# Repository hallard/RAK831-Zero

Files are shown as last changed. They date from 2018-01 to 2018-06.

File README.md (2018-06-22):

# Raspberry PI Zero RAK831 Lora Gateway Shield

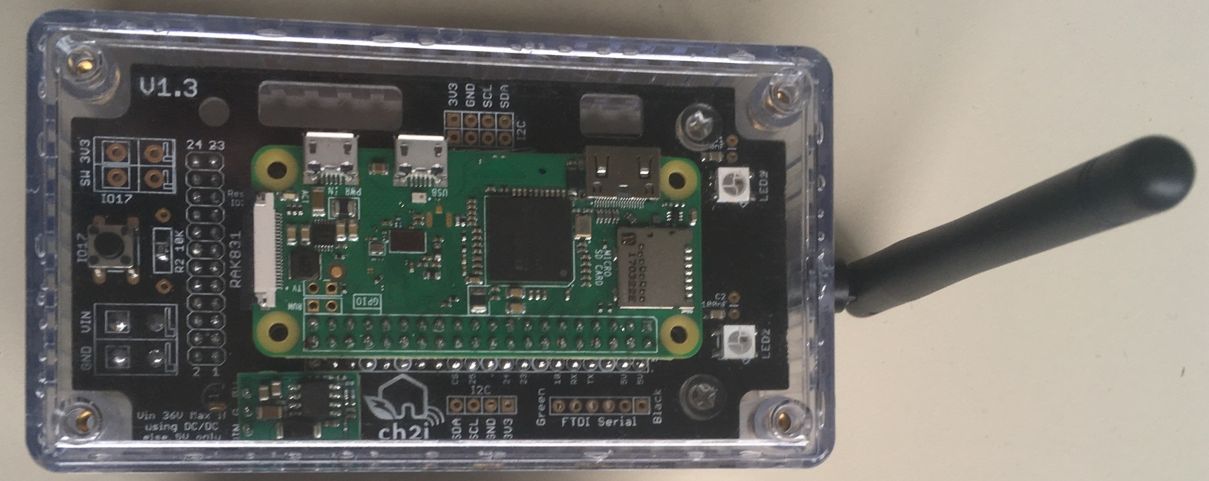
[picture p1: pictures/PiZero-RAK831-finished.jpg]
Full
     

This shield has been created to help wiring between Raspberry PI Zero and [RAK831][10] LoraWan concentrator Gateway and to be able to put the whole thing into a enclosure..

Then I decided to add some funky stuff like:

## Features (tested, working fine)

**Major updates in V1.5a**

 - Added connector to put a [Tiny GPS][46] breakout board 
 - Added switch/jumpers to select PI Serial to be connected to FTDI connector or from GPS RX/TX
 - Added footprint for RTC components or [Adafruit Breakout][47] (when used in local LoRaWAN server without Internet connexion)
 - Added a LED on ~~GPIO4~~ GPIO26 to light when GW is off so we can remove power safely (or whatever purpose)
 - Connected GPS PPS signal on GPIO4 and added a LED on this signal
 - **due to space constraints because of new features, some options to put PTH components have been removed**

**Minor tweaks in V1.4**

 - Labeling error on top silk for Murata OKI-78SR-5 (VIN VOUT were revesed) but correct on bottom silk
 - Added solder bat to be able to reverse 3V3/GND and/or SCL/SDA on I2C-1 connector 
 - Moved FTDI connector to lower position
 - Added I2C connector SILK number to identify them better
 - Added a LED on GPIO4 to light when GW is off so we can remove power safely

**Minor tweaks in V1.3b**

 - Reversed side of Murata OKI-78SR-5 to let some place for big OLED
 - Changed solder pad default power to use DC/DC 
 - Inversed the 2 OLED connectors to better seeing of RAK LED
 - Adjusted opening to see RAK LED to a better position

**Since V1.3**

 - Push button on GPIO17 to be able to shutdown PI Locally
 - Added FTDI connector to be able to take hand on PI console when in enclosure (lost network or whatever, no more need to get all off the enclosure and connect HDMI cable to see what's going on)
 - Added footprint for excellent Murata OKI-78SR-5 DC/DC 5V
 - Footprint for [RAK831][10] LoraWan concentrator (main goal)
 - I2C connectors to be able to add internal/external sensors or OLED such as BME280, SI7021, HTU21D SSD1306
 - Power with terminal block
 - 2 visual WS2812B Leds
 - Easy to build and solder, 0805 or PTH components
 - Holes to fix board on enclosure or other support
 - quick fix connector, you can plug/unplug PI Zero without soldering

Tiny GPS breakout board, buy [there][46]   
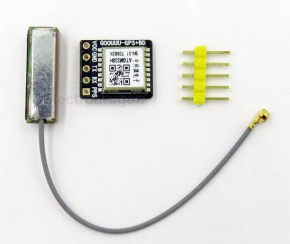
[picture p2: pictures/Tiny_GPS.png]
Tiny GPS Breakout
 

Tiny Adafruit RTC board, buy [there][47]    

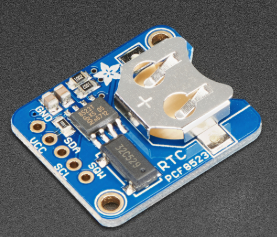
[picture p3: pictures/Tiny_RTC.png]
RTC Breakout
 

## Detailed Description

No specific documentation for now, it's just a kind of wiring helper, please see Gateway section on [TTN Learn](https://www.thethingsnetwork.org/docs/gateways/) and also on [TTN Forums](https://www.thethingsnetwork.org/forum/t/the-hard-rak831-cafe-part-2/10576/) for more information on these gateways.

### Power

You can power the board with 5V going to Raspberry PI USB power directly or connecting 5V to the terminal blocks named VIN/GND, in this case use a descent 5V power supply. 

You can also use a Murata DC/DC Step down (see BOM), in this case you can power the board from DC 7V to 36V, this is what I do each time. ~~To use this feature you need to cut the trace on bottom side of PCB that connect VIN to 5V (vout)~~.

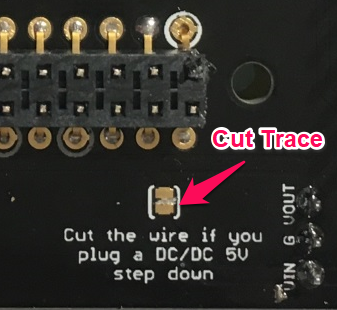
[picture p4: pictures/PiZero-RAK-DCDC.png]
    

**Since V1.3b+ the trace is not connected anymore**. This means that Vin and Vout are not connected anymore. So if you don't use DC/DC and powering with 5V, you need to put some solder on the pad to connect vout to vin (5V).

### Pushbutton

The push button is connected between 3V3 and GPIO17. GPIO17 has a 10K pull down to ground so when pressed GPIO17 become High. The button can be soldered on board, or connected to the Terminal Blocks if you want to put an external one if you have the board in a closed enclosure for example.

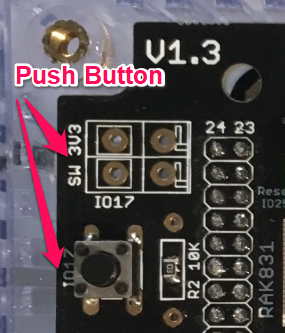
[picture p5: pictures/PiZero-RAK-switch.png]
    

Push button management is done my the monitoring service installed by the setup below

### LEDs

Led management is done my the monitoring service installed by the setup below

## Software Installation

Please follow the installation documented on the dedicated [repository][5] to install all needed and functionnal software:

- Initial configuration
- Multi Protocol Packet Forwarder
- Monitoring service (Led and Push Button)

## Schematics

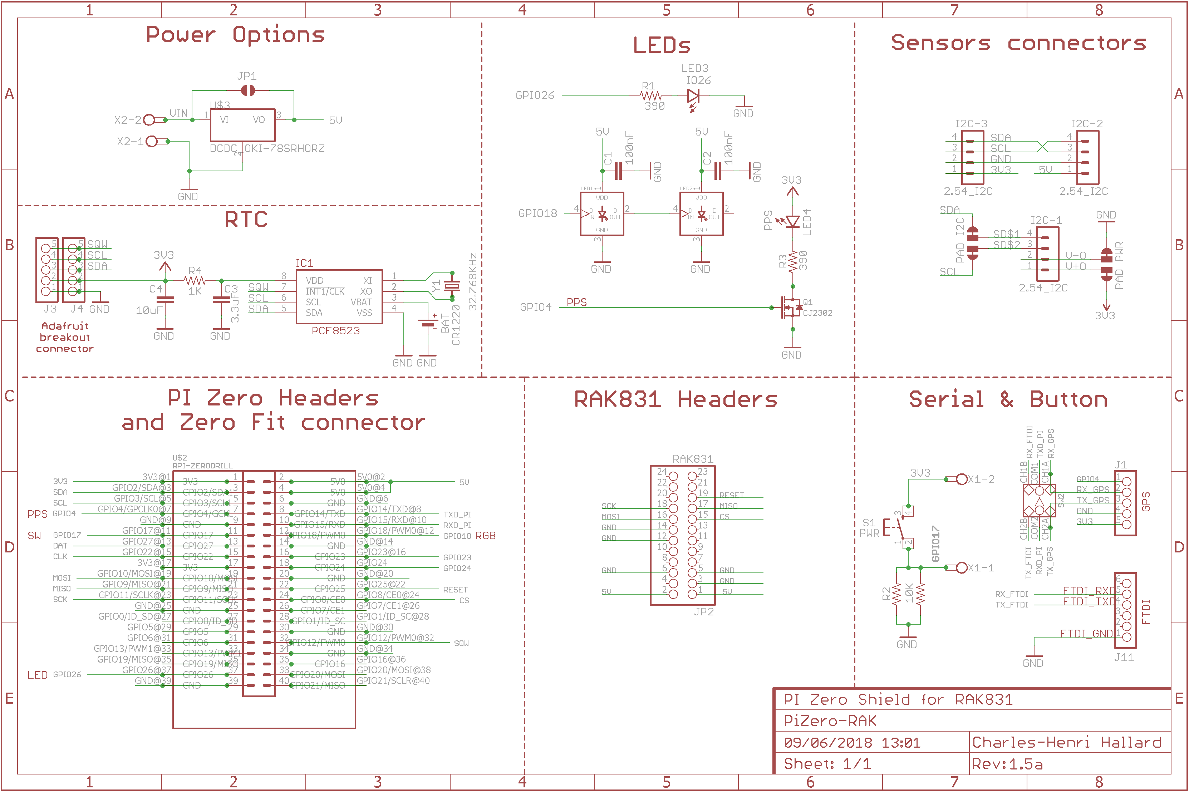
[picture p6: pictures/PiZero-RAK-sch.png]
schematic
  

## Boards 

### PCB 

**Top side**
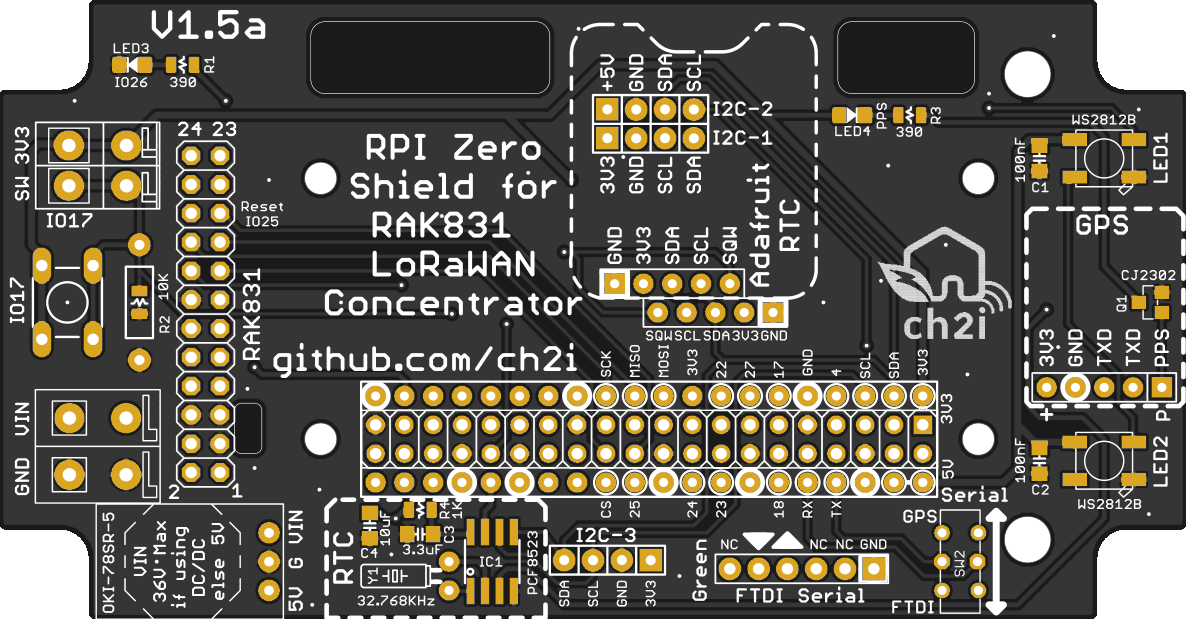
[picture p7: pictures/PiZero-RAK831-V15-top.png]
RAK831 Zero Shield V1.5 PCB Top
    

**Bottom side**
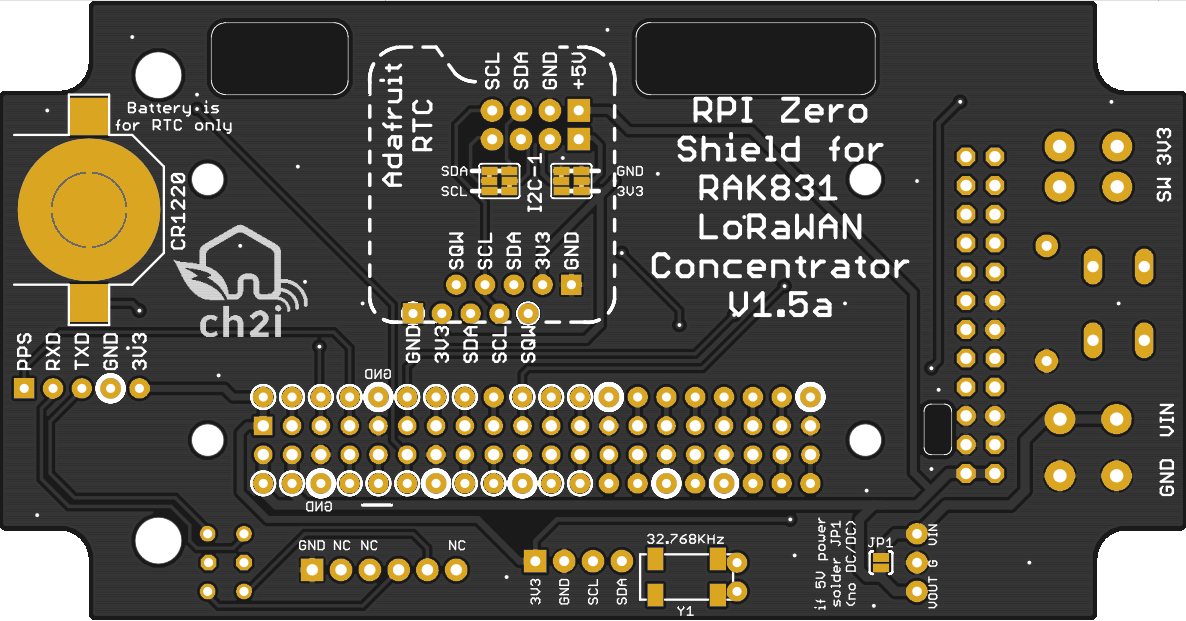
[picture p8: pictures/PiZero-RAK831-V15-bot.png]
RAK831 Zero Shield V1.5 PCB Bottom
    

### Assembled PCB (V1.3)

**Top side**
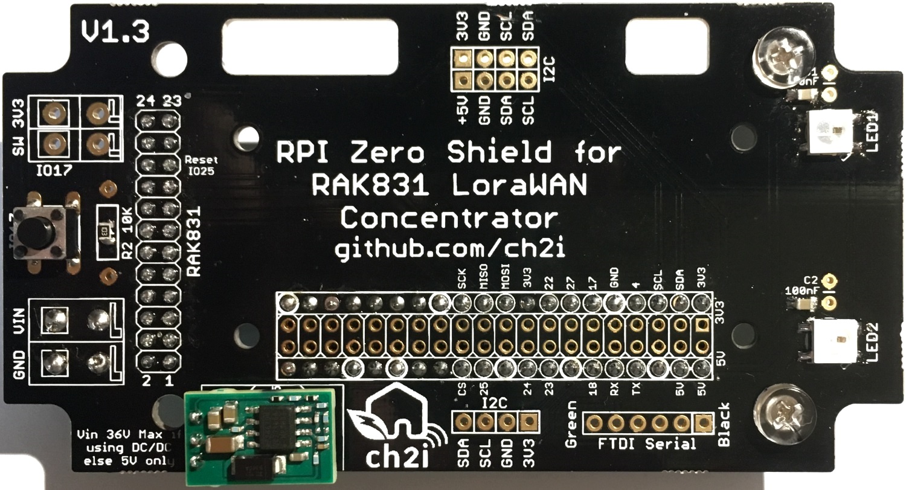
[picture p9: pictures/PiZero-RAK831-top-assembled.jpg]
PCB Top Assembled
    

**Bottom side**
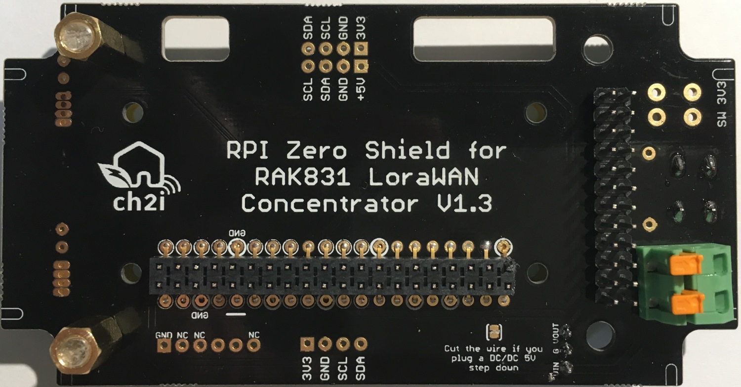
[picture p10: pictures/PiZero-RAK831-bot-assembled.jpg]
PCB Bottom Assembled
    

You can order the PCB of this board at PCBs.io 

- [V1.3][3] (obsolete)
- [V1.3b][4] (obsolete)
- [V1.4][6] 
- [V1.5a][8] Lastest one

Please not that there is special PCB version (not released yet) that fit in an indoor enclosure like the ones you can find on ebay. Search on ebay for `100x68x50mm IP66 Waterproof` or `100x68x50mm IP66 Waterproof clear` to find them.
- [V1.3][7] For outdoor enclosure (smaller PCB)

PCBs.io give me some reward when you order my designed boards from their site. This is pretty good, because I can use these rewards to create and design new boards and order boards for a discounted price, so if you don't care about PCB manufacturer please use PCBs.io.

## Assembled boards into nice enclosure 

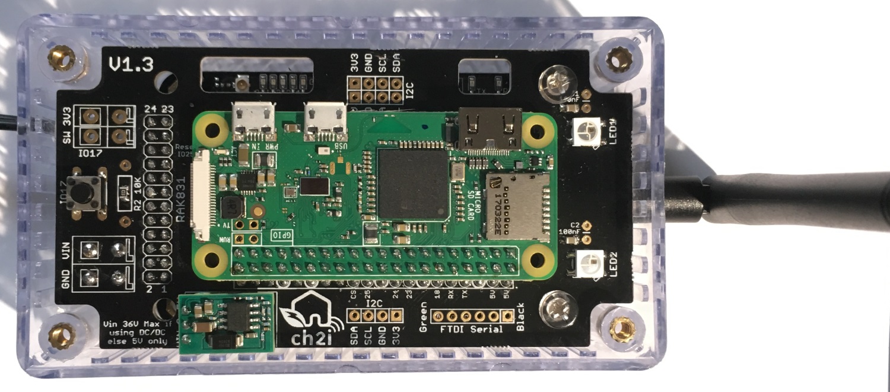
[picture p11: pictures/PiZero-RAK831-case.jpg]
     

With the samtec connector you can put the PI Zero on top or bottom, depending on your choice, just solder the sametec connector to the PCB side you need. You can also avoid connector soldering the PI directly on the board.
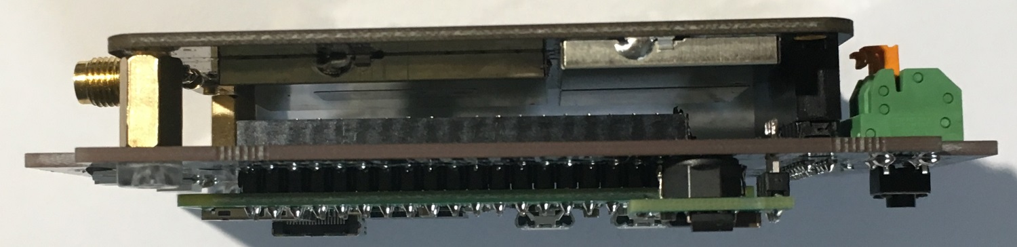
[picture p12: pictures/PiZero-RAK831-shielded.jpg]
     

And here it is near to [The things node](https://www.thethingsnetwork.org/docs/devices/node/).
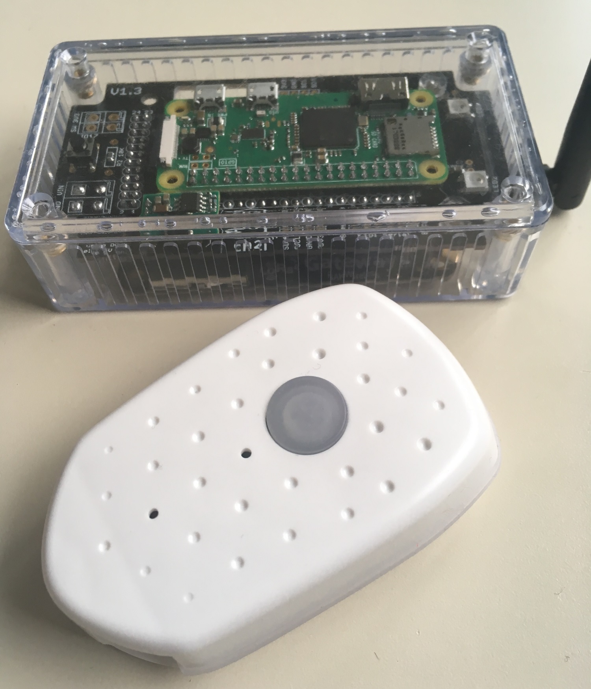
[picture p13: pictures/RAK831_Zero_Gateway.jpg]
Fully assembled with the things node
     

## Video of all

Click on image to see the video

CH2i RAK831 GW (https://www.youtube.com/watch?v=AZTomPGSOBY "CH2i RAK831 GW")

## Bill Of Material

Nothing fancy, all components are 0805 and/or PTH and can be ordered almost anywhere (digikey, mouser, radiospare, ...). 
use only what you need dependings on what you want to do. You can find lot of components on ebay or aliexpress, but since vendors are often ephemere, I put for reference the BOM on well known providers.

Here is the [octopart BOM](https://octopart.com/bom-tool/bSeZiAE7)

If you have good reference for standoff like [this][44], just let me know.

## License

   

This work is licensed under a [Creative Commons Attribution-NonCommercial 4.0 International License](http://creativecommons.org/licenses/by-nc/4.0/)    
If you want to do commercial stuff with this project, please contact [CH2i company](https://www.ch2i.eu/en#support) so we can organize an simple agreement.

# Misc

See news and other projects on my [blog][1] 
 
[1]: https://hallard.me
[3]: https://PCBs.io/share/rpqDd
[4]: https://PCBs.io/share/z722g
[6]: https://PCBs.io/share/4qKoO
[7]: https://PCBs.io/share/zvYLj
[8]: https://www.pcbs.io/share/rwjd1

[5]: https://github.com/ch2i/LoraGW-Setup
[10]: http://www.rakwireless.com/en/WisKeyOSH/RAK831
[44]: https://www.ebay.com/itm/162036913864?var=461005633671
[45]: http://www2.mouser.com/ProductDetail/Murata-Power-Solutions/OKI-78SR-5-15-W36H-C/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
[46]: http://www.electrodragon.com/product/gnss-module-atgm336h/
[47]: https://www.adafruit.com/product/3295

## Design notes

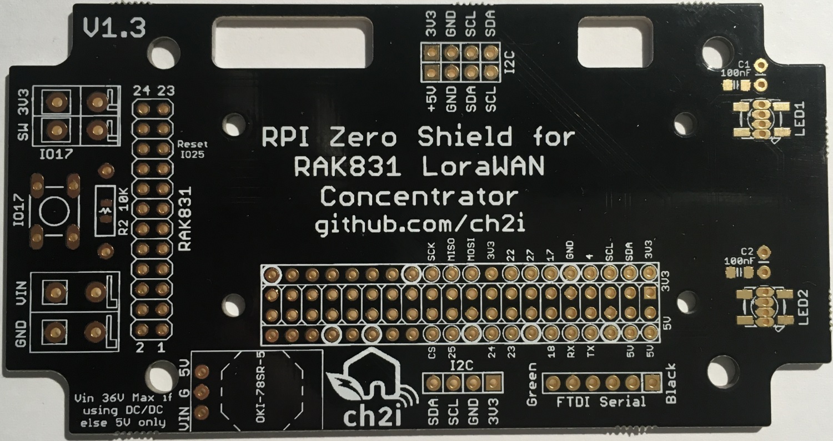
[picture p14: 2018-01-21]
pictures/PiZero-RAK831-top.jpg

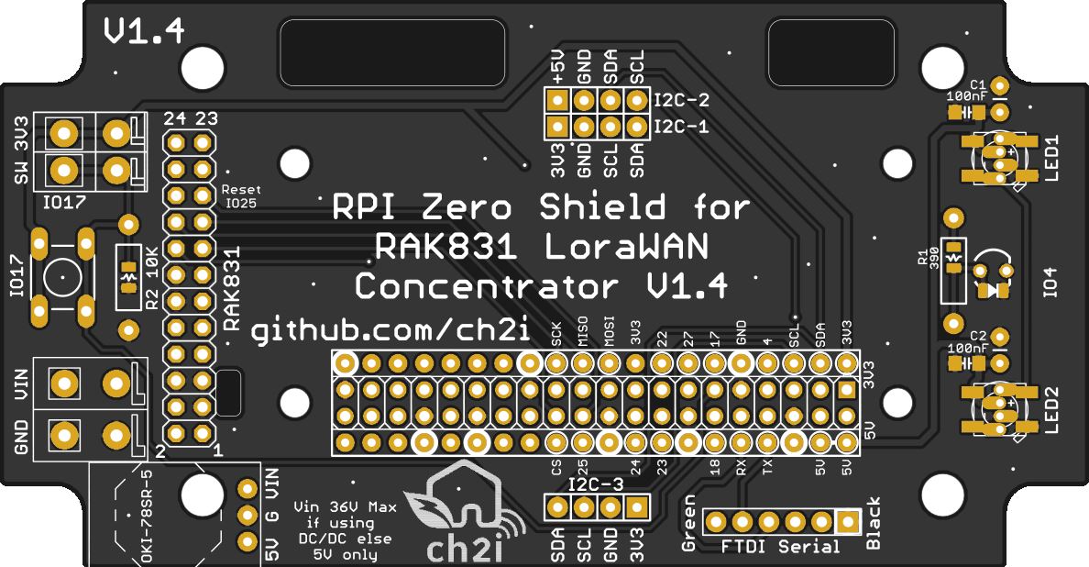
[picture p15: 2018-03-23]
pictures/PiZero-RAK831-V14-top.jpg

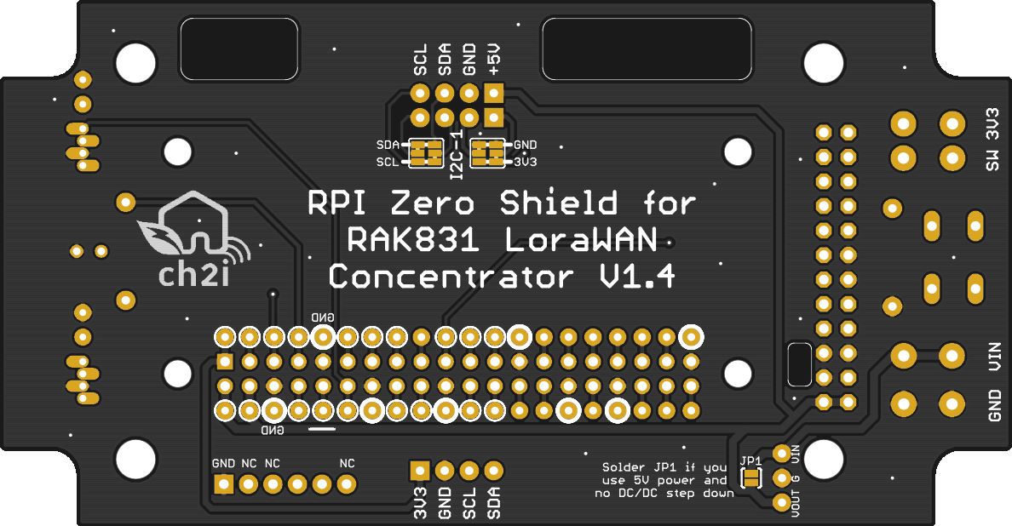
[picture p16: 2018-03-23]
pictures/PiZero-RAK831-V14-bot.jpg

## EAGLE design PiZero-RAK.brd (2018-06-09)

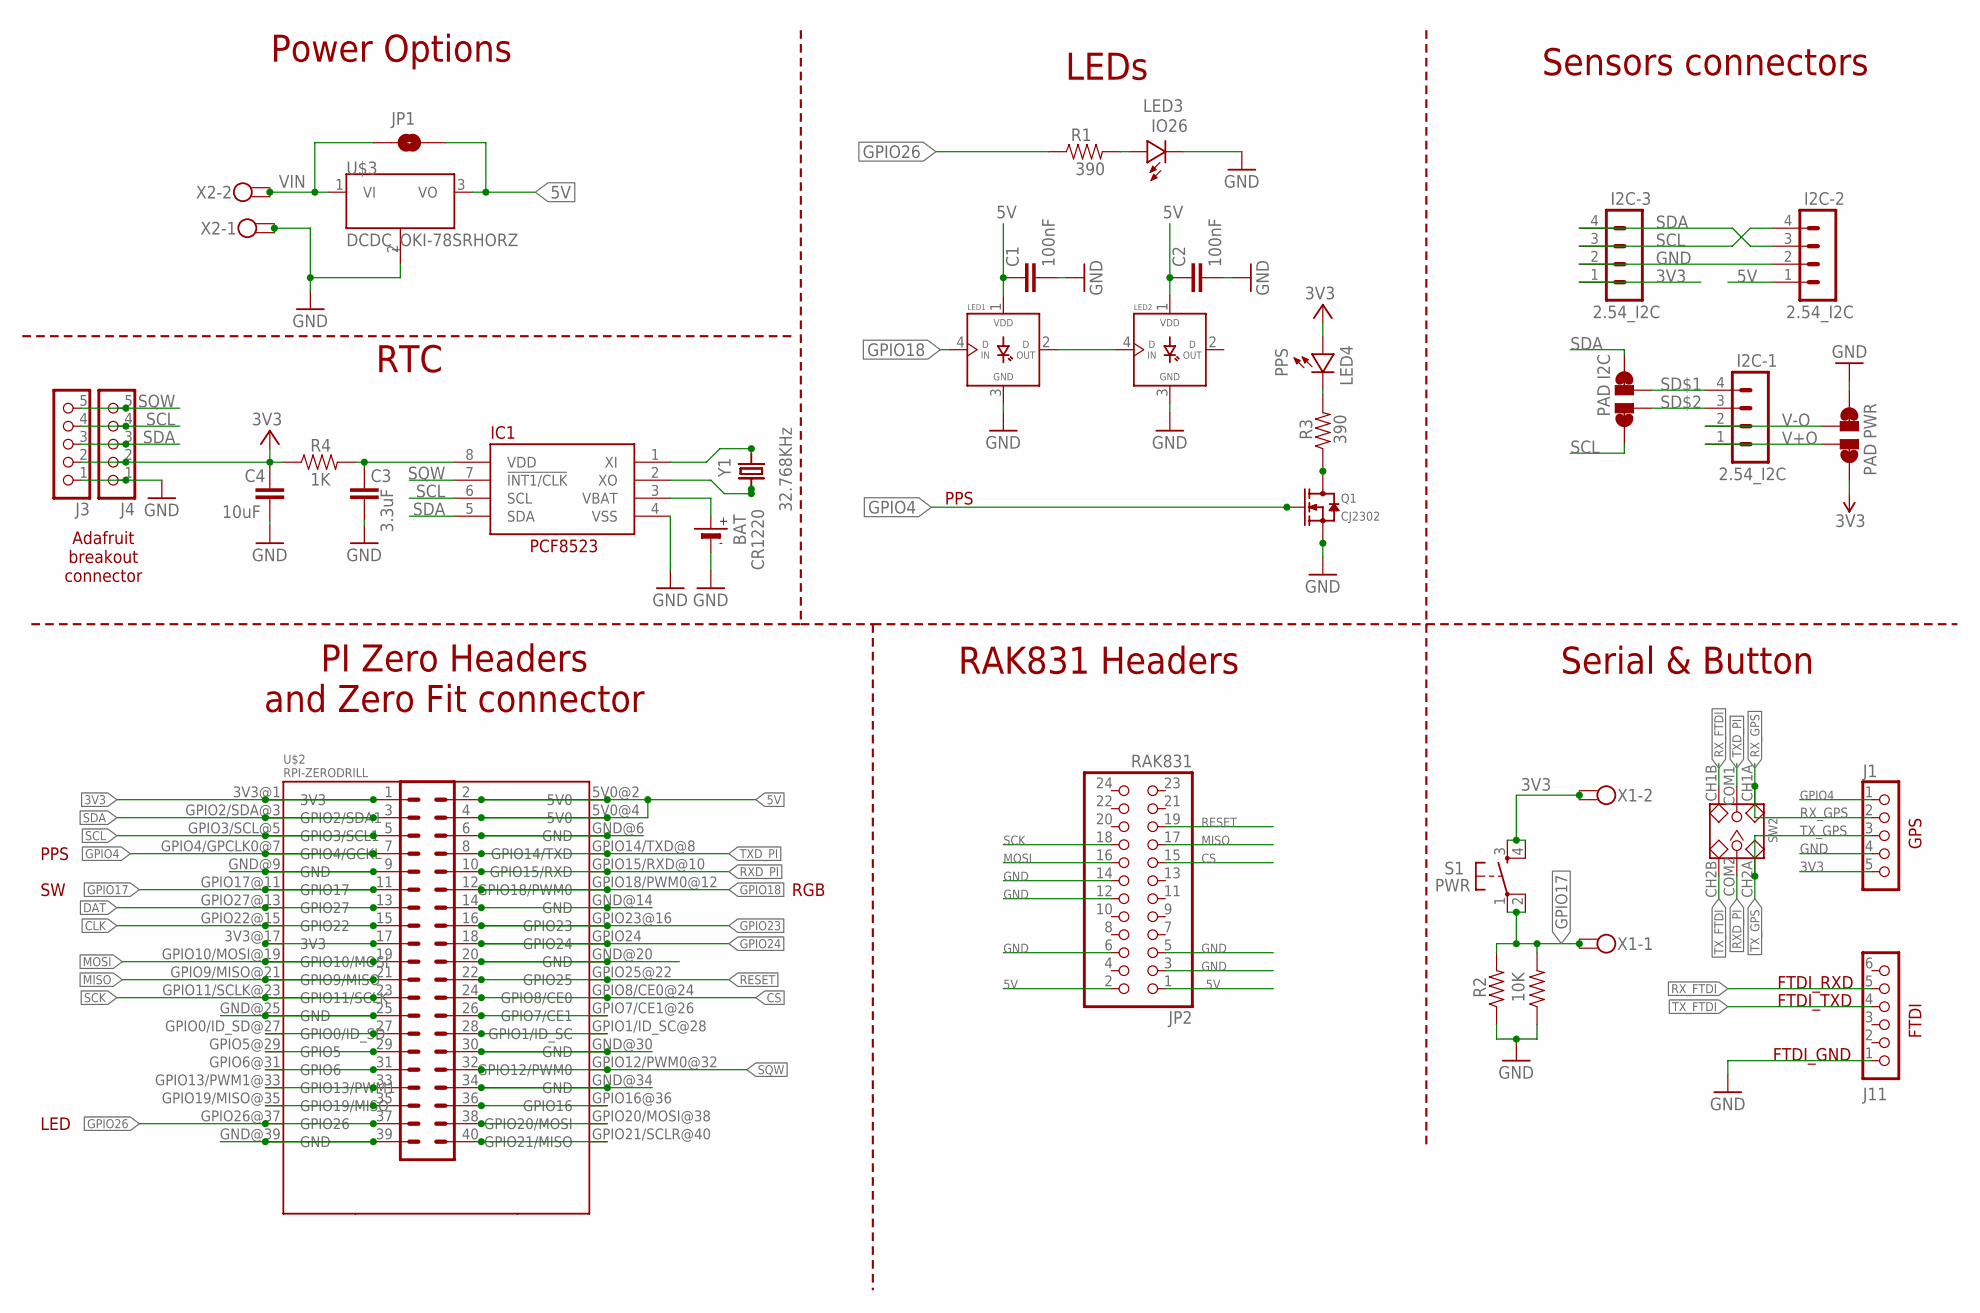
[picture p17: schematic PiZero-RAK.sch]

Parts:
BAT: CR1220
C1, C2: 100nF; 0805-CAP-LARGEPADS
C3: 3.3uF; 0805-CAP-LARGEPADS
C4: 10uF; 0805-CAP-LARGEPADS
I2C-1, I2C-2, I2C-3: 2.54_I2C; 1X04_NO_LOCK
IC1: PCF8523; SOIC8_150MIL
J1, J3, J4: CON_HEADER_1X05-PTH; M1X5
J2: CONN_20X2HLE; 2X20-HLE
J11: CON_HEADER_1X06-PTH; M1X6
JP1: JUMPER-PAD-2-NOYES_SILK; PAD-JUMPER-2-NO_YES_SILK
JP2: RAK831; 2X12
LED1, LED2: WS2812BLONG; WS2812B-LONG
LED3: IO26; 0805-LED-LARGEPADS
LED4: PPS; 0805-LED-LARGEPADS
Q1: CJ2302; SOT-23
R1, R3: 390; 0805-RES
R2: 10K; AXIAL-0.4
R4: 1K; 0805-RES
R105: RESISTOR0805-RES; 0805-RES
S1: PWR; TAC-SWITCH-PTH
SW2: DIP-TOGGLE-SWITCH-2CH-(2X3P-2.54); SW6-2.54-9.0X3.5X3.2+2.0MM
U$2: RPI-ZERODRILL; RPI-ZERO-DRILLS
U$3: DCDC_OKI-78SRHORZ; OKI-78SRH
U$4: PAD PWR; PAD-JUMPER-SWAP
U$5: PAD I2C; PAD-JUMPER-SWAP
X1: SPTAF_23.5; FFKV2_35
X2: SPTAF_25.0MM; SPTAF_2X50
Y1: 32.768KHz; TC26H
Y2: CRYSTAL8X3.8SMT; CRYSTAL_8X3.8

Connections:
3V3: C4.1, I2C-3.1, J1.5, J2.1, J3.2, J4.2, LED4.PLUS, R4.1, S1.3, S1.4, U$2.3V3@1 (3V3), U$4.4, U$4.44 (4), X1.2 (1), X1.2A (2)
3V3@17: J2.17, U$2.3V3@17 (3V3)
5V: C1.1, C2.1, I2C-2.1, J2.2, J2.4, JP1.2, JP2.1, JP2.2, LED1.1 (VDD), LED2.1 (VDD), U$2.5V0@2 (5V0), U$2.5V0@4 (5V0), U$3.3 (VO)
CLK: J2.15, U$2.GPIO22@15 (GPIO22)
CS: J2.24, JP2.15, U$2.GPIO8/CE0@24 (GPIO8/CE0)
DAT: J2.13, U$2.GPIO27@13 (GPIO27)
GND: BAT.-, C1.2, C2.2, C3.2, C4.2, I2C-2.2, I2C-3.2, IC1.4 (VSS), J1.4, J2.6, J2.9, J2.14, J2.20, J2.25, J2.30, J2.34, J2.39, J3.1, J4.1, J11.1, JP2.3, JP2.5, JP2.6, JP2.12, JP2.14, LED1.3 (GND), LED2.3 (GND), LED3.MINUS, Q1.2 (S), R2.P$1 (1), R105.1, U$2.GND@6 (GND), U$2.GND@9 (GND), U$2.GND@14 (GND), U$2.GND@20 (GND), U$2.GND@25 (GND), U$2.GND@30 (GND), U$2.GND@34 (GND), U$2.GND@39 (GND), U$3.2 (GND), U$4.1, U$4.11 (1), X2.1, X2.1A (2)
GPIO4: J1.1, J2.7, Q1.1 (G), U$2.GPIO4/GPCLK0@7 (GPIO4/GCKL)
GPIO17: J2.11, R2.P$2 (2), R105.2, S1.1, S1.2, U$2.GPIO17@11 (GPIO17), X1.1, X1.1A (2)
GPIO18: J2.12, LED1.4 (DIN), U$2.GPIO18/PWM0@12 (GPIO18/PWM0)
GPIO19: J2.35, U$2.GPIO19/MISO@35 (GPIO19/MISO)
GPIO23: J2.16, U$2.GPIO23@16 (GPIO23)
GPIO24: J2.18, U$2.GPIO24
GPIO26: J2.37, R1.1, U$2.GPIO26@37 (GPIO26)
MISO: J2.21, JP2.17, U$2.GPIO9/MISO@21 (GPIO9/MISO)
MOSI: J2.19, JP2.16, U$2.GPIO10/MOSI@19 (GPIO10/MOSI)
unnamed: J2.26, U$2.GPIO7/CE1@26 (GPIO7/CE1)
unnamed: LED3.PLUS, R1.2
unnamed: IC1.1 (XI), Y1.1, Y2.P$4 (2)
unnamed: Q1.3 (D), R3.1
unnamed: J2.28, U$2.GPIO1/ID_SC@28 (GPIO1/ID_SC)
unnamed: J2.36, U$2.GPIO16@36 (GPIO16)
unnamed: J2.38, U$2.GPIO20/MOSI@38 (GPIO20/MOSI)
unnamed: J2.40, U$2.GPIO21/SCLR@40 (GPIO21/MISO)
unnamed: J2.27, U$2.GPIO0/ID_SD@27 (GPIO0/ID_SD)
unnamed: J2.29, U$2.GPIO5@29 (GPIO5)
unnamed: J2.31, U$2.GPIO6@31 (GPIO6)
unnamed: J2.33, U$2.GPIO13/PWM1@33 (GPIO13/PWM1)
unnamed: LED4.MINUS, R3.2
unnamed: IC1.2 (XO), Y1.2, Y2.P$1 (1)
unnamed: LED1.2 (DOUT), LED2.4 (DIN)
RESET: J2.22, JP2.19, U$2.GPIO25@22 (GPIO25)
RXD_PI: J2.10, SW2.COM2, U$2.GPIO15/RXD@10 (GPIO15/RXD)
RX_FTDI: J11.5, SW2.CH1B
RX_GPS: J1.2, SW2.CH1A
SCK: J2.23, JP2.18, U$2.GPIO11/SCLK@23 (GPIO11/SCLK)
SCL: I2C-2.4, I2C-3.3, IC1.6 (SCL), J2.5, J3.4, J4.4, U$2.GPIO3/SCL@5 (GPIO3/SCL1), U$5.1, U$5.11 (1)
SD$1: I2C-1.4, U$5.3
SD$2: I2C-1.3, U$5.2
SDA: I2C-2.3, I2C-3.4, IC1.5 (SDA), J2.3, J3.3, J4.3, U$2.GPIO2/SDA@3 (GPIO2/SDA1), U$5.4, U$5.44 (4)
SQW: IC1.7 (!INT1/CLK), J2.32, J3.5, J4.5, U$2.GPIO12/PWM0@32 (GPIO12/PWM0)
TXD_PI: J2.8, SW2.COM1, U$2.GPIO14/TXD@8 (GPIO14/TXD)
TX_FTDI: J11.4, SW2.CH2B
TX_GPS: J1.3, SW2.CH2A
V+O: I2C-1.1, U$4.3
V-O: I2C-1.2, U$4.2
VBAT: BAT.+$1 (+), IC1.3 (VBAT)
VDD: C3.1, IC1.8 (VDD), R4.2
VIN: JP1.1, U$3.1 (VI), X2.2 (1), X2.2A (2)

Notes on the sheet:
RAK831 Headers
Power Options
Serial & Button
LEDs
Sensors connectors
PI Zero Headers and Zero Fit connector
FTDI_RXD
FTDI_TXD
FTDI_GND
GPS
FTDI
PPS
RGB
LED
RTC
Adafruit breakout connector

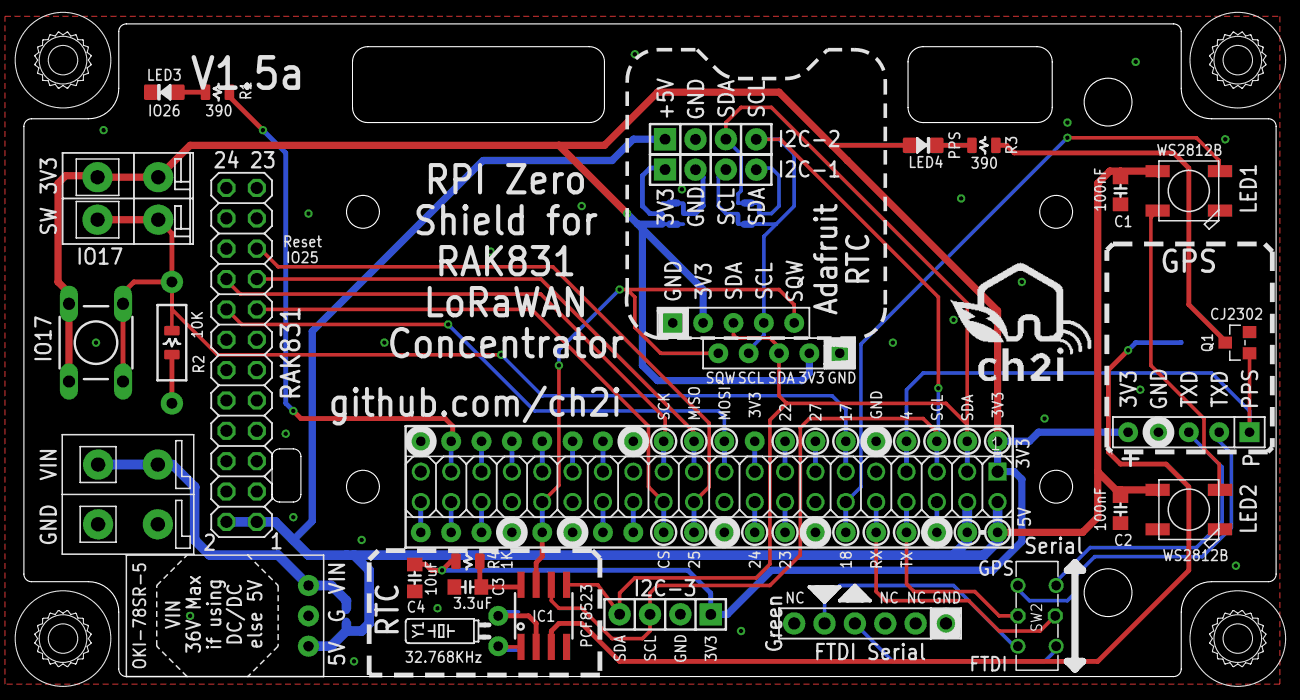
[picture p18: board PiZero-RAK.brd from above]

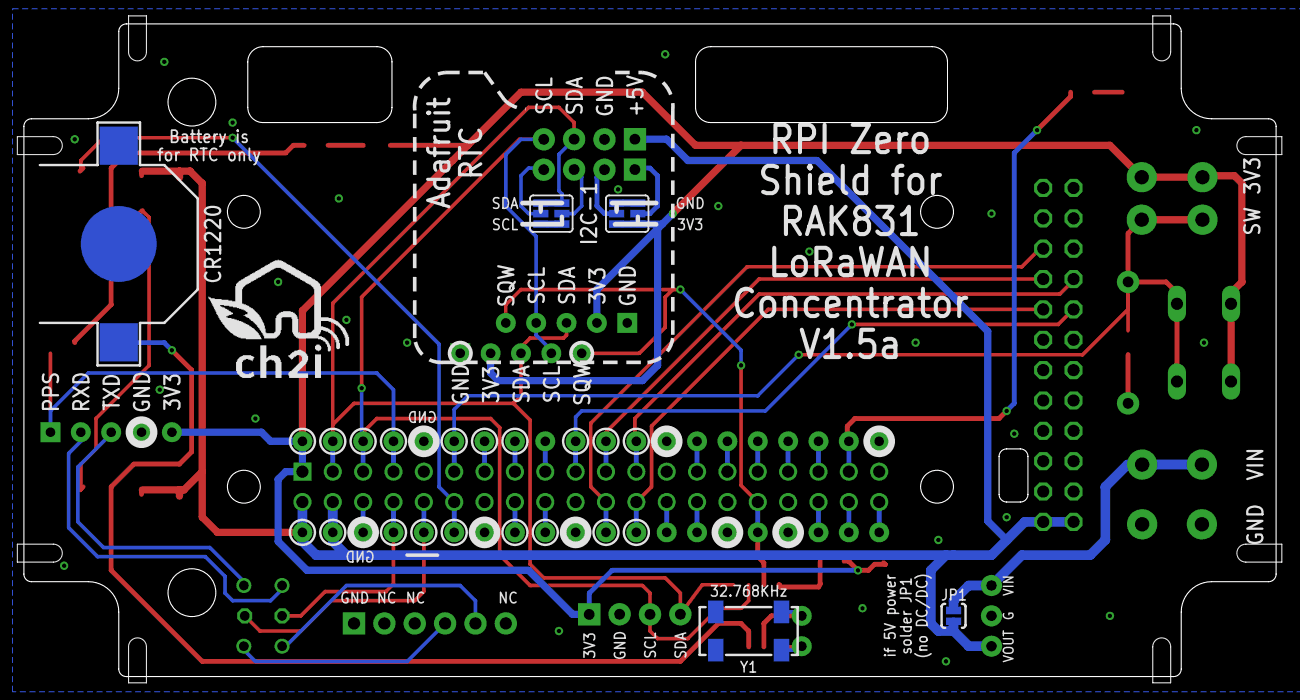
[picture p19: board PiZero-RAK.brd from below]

Board: 2 copper layers, 104.8 x 54.6 mm, 39 parts (6 on the bottom side), 49 nets.

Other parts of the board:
U$1, U$9: LOGO_CH2I_110MM
U$10: ENCLOSURE_1591B

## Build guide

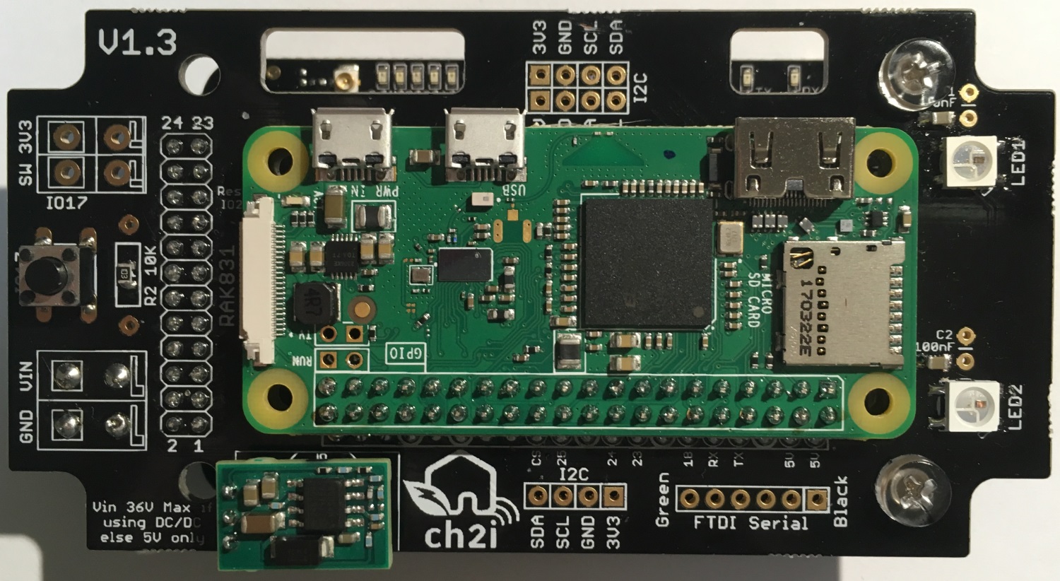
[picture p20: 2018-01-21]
pictures/PiZero-RAK831-assembled.jpg

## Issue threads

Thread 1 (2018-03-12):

pinout unclear in version 1.2

SensorsIot, 2018-03-12:
Hi Charles
I used your board to build a Gateway, but it does not work (the concentrator cnaoot be connected, the rest works ok). When I checked the PCB I found some strange things. On the 1.3a version of he Eagle files Pin 1 and 2 are 5V. On my board 23 and 24 are connected to 5 volts. Somehow everything seems mirrored. What is my mistake? The Neopixels are on the side of the RPI and the concentrator below your board.

hallard, 2018-03-13:
Andreas,
Yes before V1.3 the RAK831 concentrator board need to be plugged on top (concentrator above). that's not cool and my mistake.So that's why some silk numbering are wrong.
So to Resume on V1.2 just plug the RAK on TOP and it works, don't bother with silk numbering

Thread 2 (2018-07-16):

Ethernet jack with PoE

jpmeijers, 2018-07-16:
Is there any chance you can add ethernet to the backplane, splitting out the passice PoE lines to the DC/DC, and the data lines to a usb ethernet module?

edude03, 2018-07-30:
Standard PoE would be nice as well

jpmeijers, 2018-07-30:
Yes. 802.3af would be nice, but more expensive to implement.

hallard, 2018-09-17:
@Guys,
I designed this board to directly fit into the enclosure I'm using. Adding this hardware would oversize and not fit into the enclosure.
Anyway you can still use the board on a Raspberry (or clone) with Ethernet and just add POE splitter?

Closed 2018-09-17.

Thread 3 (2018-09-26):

missing items from BOM

lunarHonour, 2018-09-26:
Hi, I just assembled a v1.5a board but noticed I was missing some items that were not on the BOM (which I ordered from).

Can you please help me figure out what:

LED3, LED4, R1, R3 and Q1 should be?

The CR1220 holder was also missing but that is easier to guess.

Also the "R30-3000602" standoff is too short as it is only 6MM and I think these should be 2x instead of 1x on the BOM.
Thanks!!

hallard, 2018-09-30:
Hi,
Thanks for pointing that out, the BOM file as been updated.
https://octopart.com/bom-tool/bSeZiAE7

Closed 2018-09-30.

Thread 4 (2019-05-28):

Detail pictures of 1.5A

VladoPortos, 2019-05-28:
Hello,
Finally PCB of 1.5a version arrived home :) do you have by any chance detailed pictures of the PCB with components ? I'm trying to figure out what is needed and what is not to be there. For example if I use the Adafruit RTC, I will not need to add anything to the RTC block on the oposite side right ? Same with CR1220 since the Adafruit have its own battery ( I think ).  Also what is the I2C-1 on the Bottom side of the Adafruit RTC block ( checking the schema looks like the I2C-1 to 3 is for sensors) ? What is the IO17 ( SW 3V3) ?

If I'm going to use just 5V adapter ( or the DC/DC) is the rpi powered from pins ?

Sorry for so much questions, just want to make it right :D
Thanks.

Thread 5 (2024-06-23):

Dead Link

pacmac, 2024-06-23:
Seems that the link to buy the board is no longer correct:

https://www.pcbs.io/share/rwjd1

That points to an expired domain pointer, how can I purchase the board ?

hallard, 2024-06-23:
Hi,
I may have some spare PCB or fully assembled even fully assembled gateways with enclosure that I do not use anymore which do you prefer?

pacmac, 2024-06-23:
thanks so much, shipping costs are always a problem, so enclosures are not a good idea, I have lots in my stock.

Do you have a V1.5 board with RAK831 ??

And as that site appears to be dead, will you get another PCB manufacturer to make them ?

I am in Singapore.

Thanks again for the quick response.

hallard, 2024-06-23:
Correct no enclosure to your country need to be flat enveloppe ;)
I'll check at the office tomorrow what I got, but pretty sure assembled v1.5 plus RAK831

pacmac, 2024-06-23:
Thanks so much.

pacmac, 2024-06-23:
but if you have a board with RAK831 then it would save me ordering from 2 sources.

pacmac, 2024-06-23:
can you give me the link to the PCB on JLCPCB as they dont appear to have a search button ?

hallard, 2024-06-23:
Sorry there is no link you need to send gerbers files to them (I need to put them on this repo is needed) and make a classic PCB order, anyway you can also send brd file from this repo to OSHPARK and get 3 pcb done.

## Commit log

2018-01-21 Added connector info
2018-01-21 Cosmetic updates
    [PiZero-RAK.sch]
2018-02-05 Bump to V1.3b
    [PiZero-RAK.brd, PiZero-RAK.sch]
2018-02-05 Added V1.3b PCBs.io link
2018-03-23 Bump to V1.4
    [PiZero-RAK.brd, PiZero-RAK.sch]
2018-03-23 Added link to outdoor PCB version
2018-06-08 Bump to V1.5
    [PiZero-RAK.brd, PiZero-RAK.sch]
2018-06-09 Bump to V1.5a
    [PiZero-RAK.brd, PiZero-RAK.sch]
2018-06-22 Fixed BOM link

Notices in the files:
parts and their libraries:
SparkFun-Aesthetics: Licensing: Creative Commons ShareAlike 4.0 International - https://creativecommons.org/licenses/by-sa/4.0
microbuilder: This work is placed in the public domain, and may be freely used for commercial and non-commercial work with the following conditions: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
